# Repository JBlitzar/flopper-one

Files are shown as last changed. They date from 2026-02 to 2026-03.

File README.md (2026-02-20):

# flopper-one

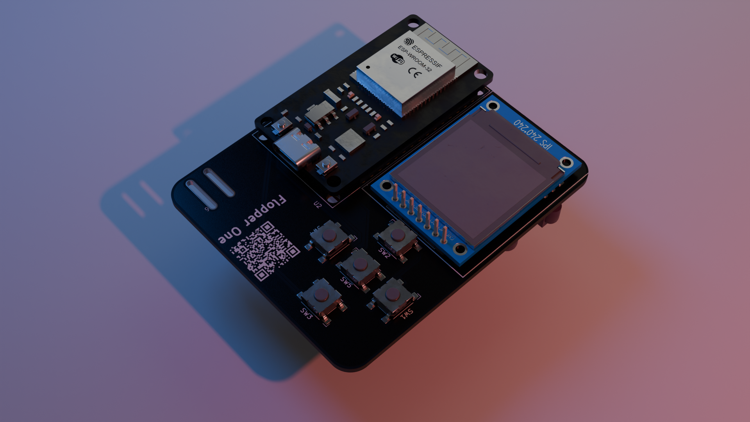
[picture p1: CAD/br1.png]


<!-- <img src="CAD/br2.png"> -->

<table width="100%">
    <tr>
        <td>
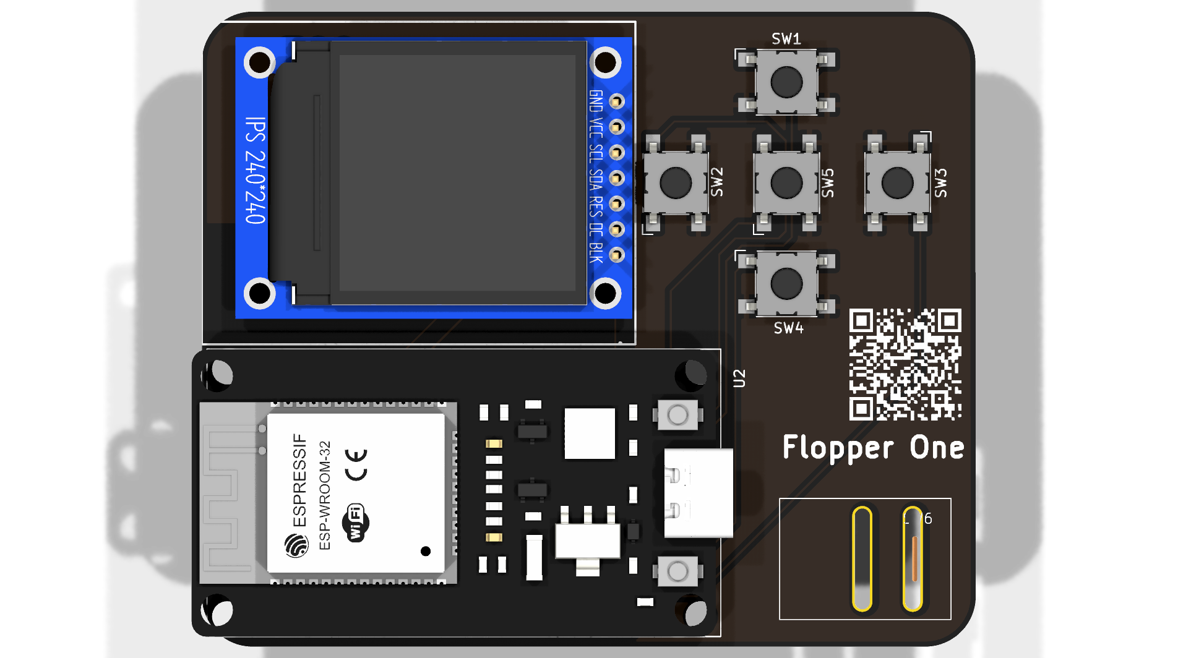
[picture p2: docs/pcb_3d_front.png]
            
        </td>
        <td>
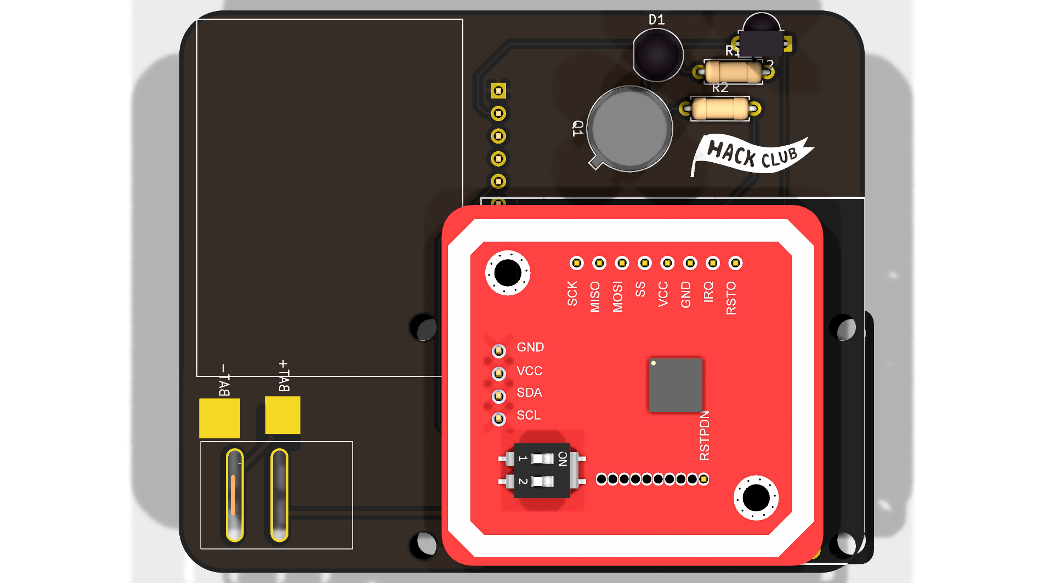
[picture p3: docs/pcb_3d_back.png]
            
        </td>
    </tr>
</table>

Flipper zero-type firmware with an ESP32. Featuring IR, NFC, BLE, wifi, with a dpad and an lcd display. Not designed using any guide!

I've always thought that the flipper zero was pretty cool, but the $200 price point made it seem out of reach.

I joined up blueprint, made the [hackpad](https://github.com/JBlitzar/blitzypad), learned a lot and had a lot of fun.

Then I saw the [sorta flipper zero](https://blueprint.hackclub.com/projects/7192). This was truly inspring. I saw it, and I thought to myself, _I could totally do that_. And it turns out I have like half the parts! The ESP has wifi and bluetooth built in (you usually need to pay like $60 extra for wifi on a flipper), all that's left is to add... all the other stuff.

Since this is my second PCB project, I opted for a module build. In the end, this made the pcb quite crowded and taught me a lot about good routing (and I still had to use the smd TP4056 IC, you'll see later)

Basically, after the ESP, we need a UI, IR, NFC, and RFID.

The UI is some buttons in a dpad and a display.

IR is incredibly easy. It's literally an LED (with some passives sprinkled in), and then a TSOP38238 to recieve.

For NFC/RFID, I opted for the PN532 module. I breifly entertained the idea of using the bare PN532 chip and fully integrating it, but the [datasheet](https://www.nxp.com/docs/en/nxp/data-sheets/PN532_C1.pdf) is 222 pages long and the application circuit (page 212, figure 51) seems pretty involved if I do say so myself.

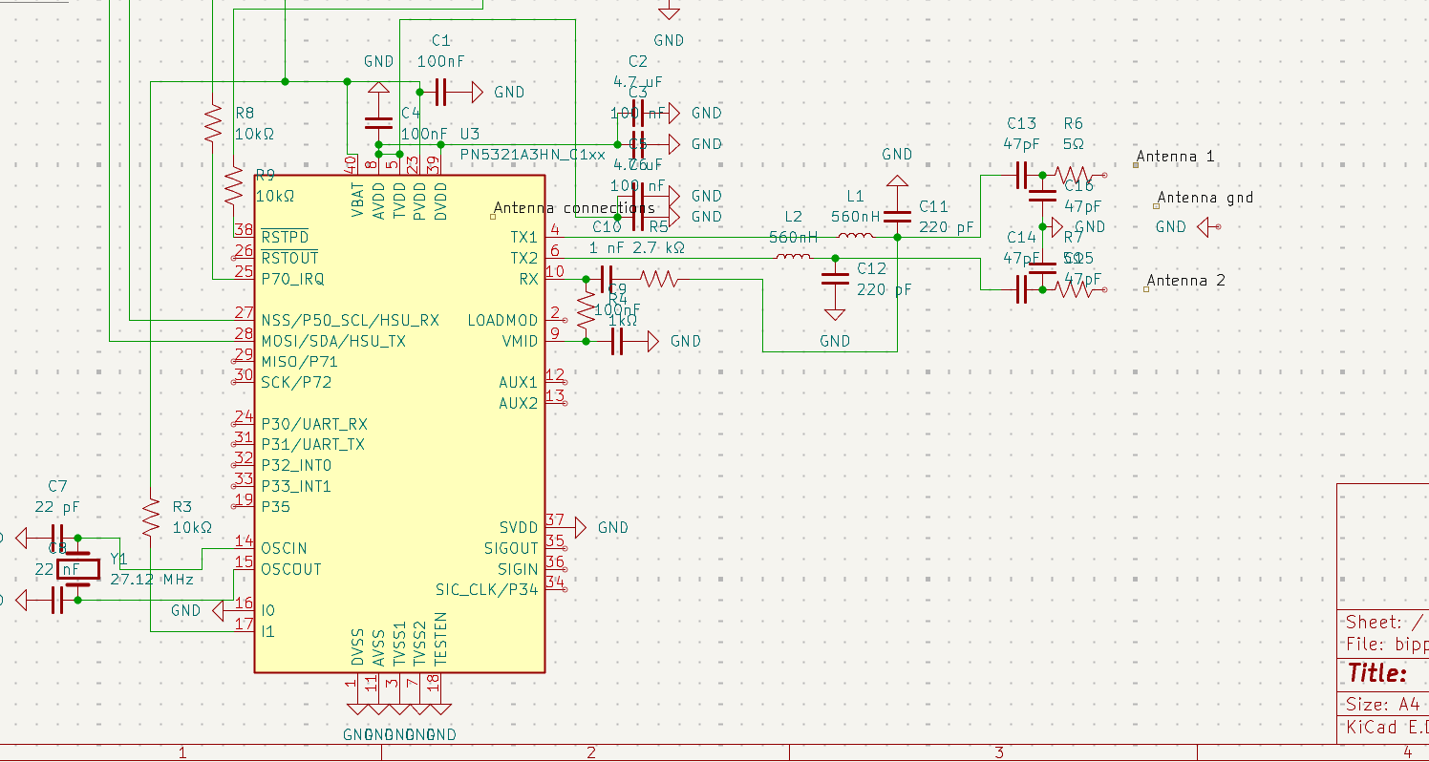
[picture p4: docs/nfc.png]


> _incomplete nfc circuit... yeah its pretty complicated_
>
> At this point it's cheaper AND smaller to just use the module. So that's what I did

Then I thought it'd be fun to add power management. _"fun."_ If only it was simple [like the xiao](https://wiki.seeedstudio.com/xiao_nrf54l15_sense_getting_started/#battery-powered-board)! I added the TP4056 IC because I was feeling fancy. I asked on slack, and it turns out you need a boost converter. To get your 3.7v battery up to 5v... so that it can go back down to 3.3v. I used a module for the boost converter. But I still got to add fun charging status LEDs! Also I got the "opportunity" to google translate Chinese datasheets.

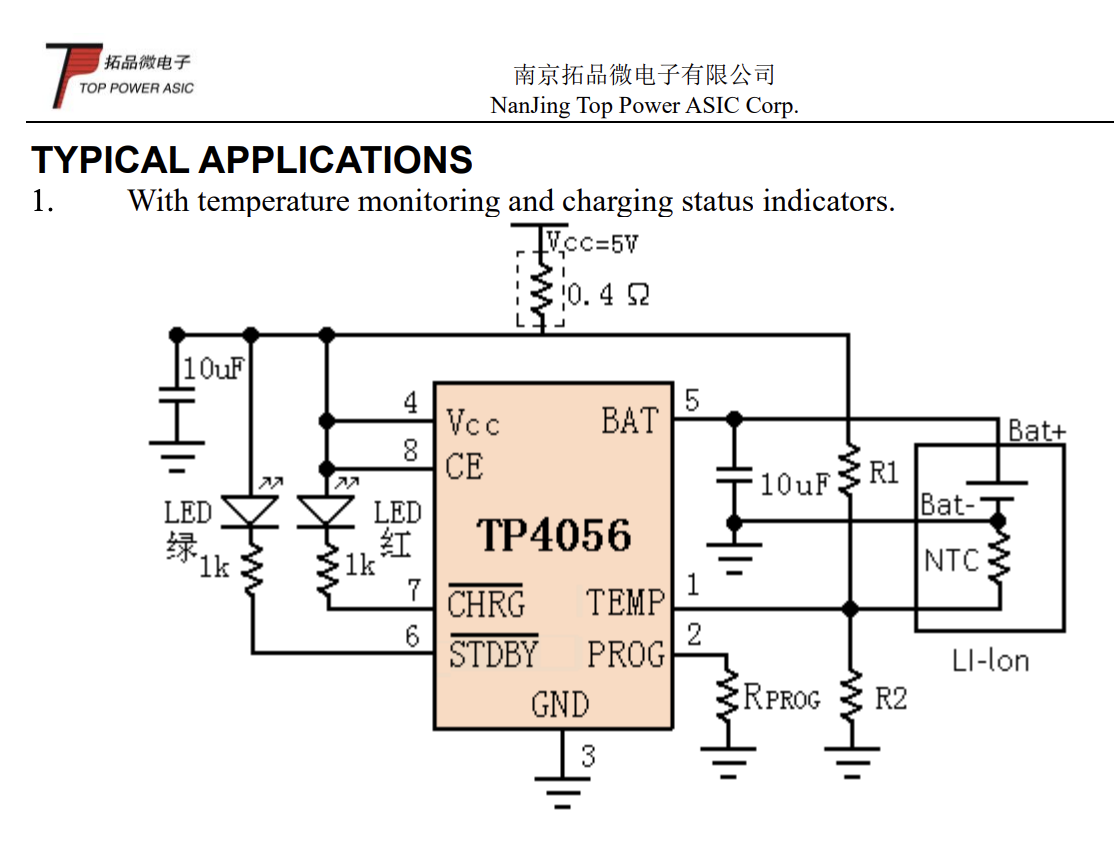
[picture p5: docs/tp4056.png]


I also discovered some... interesting hacks like how the VIN pin on the esp [is actually 5v out](https://esp32.com/viewtopic.php?t=11904) when the usb is plugged in. Meaning we can charge from VIN... and then later discharge also to VIN.

I added a physical switch to prevent backflow. So congratulations, users are now trusted with power supply logic!

## Schematic



## Assembly

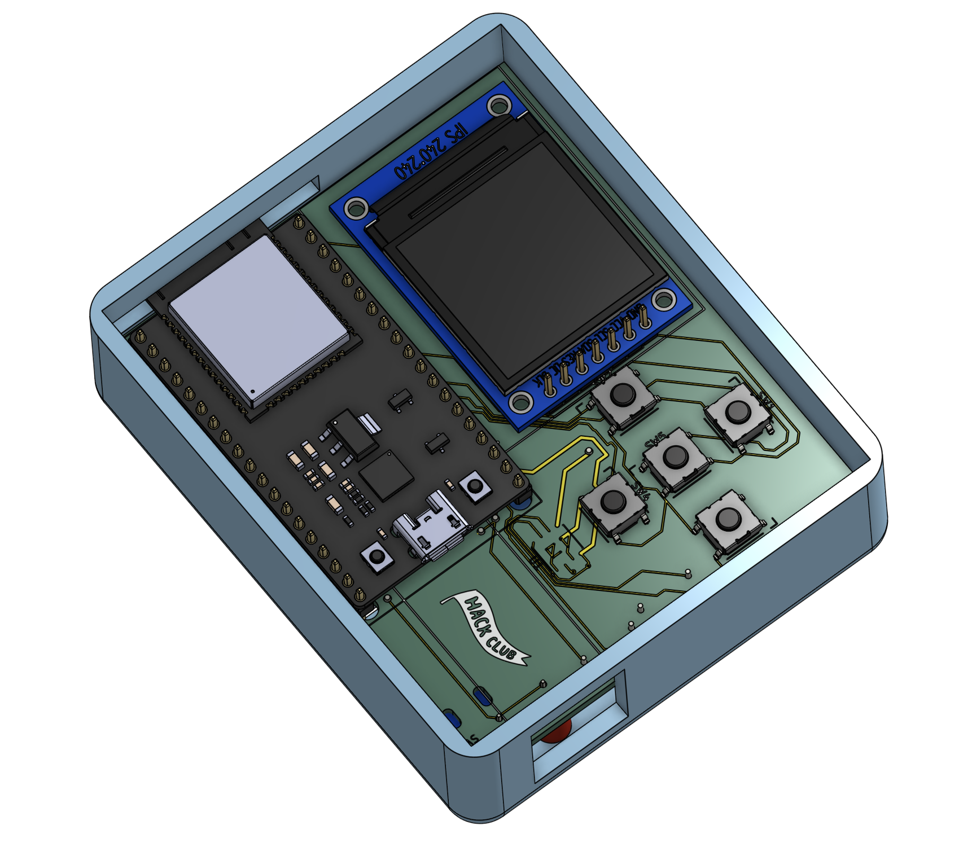
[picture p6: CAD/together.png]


IMPORTANT: See [CAD/README.md](CAD/README.md) for notes.

## PCB



## BOM in table format

see BOM.csv.

This BOM format has been [approved](https://hackclub.slack.com/archives/C09CMJV6V6K/p1770569396266989) by the blueprint team

| Item | Link | Cost  | Amount | total cost of | total | Gotten? |
| --- | --- | ----- | --- | --- | ----- | --- |
| | | | | | 32.15 | FALSE |
| esp32 wroom | already own | 0 | 1 | 0 | | TRUE |
| TSOP38238 | https://www.lcsc.com/product-detail/C141632.html | 0.73  | 1 | 0.73 | | FALSE |
| TSAL6200 | https://www.lcsc.com/product-detail/C55528.html | 0.83  | 1 | 0.83 | | FALSE |
| PN532 | https://www.aliexpress.us/item/3256806254348567.html  | 0.99  | 1 | 0.99 | | FALSE |
| ST7789 | https://www.aliexpress.us/item/2255799995721426.html  | 3.57  | 1 | 3.57 | | FALSE |
| 5x b3fs | https://www.lcsc.com/product-detail/C271750.html | 1.07  | 1 | 1.07 | | FALSE |
| 5x TP4056 (moq) | https://www.lcsc.com/product-detail/C16581.html | 0.91  | 1 | 0.91 | | FALSE |
| lipo battery | already own | 0 | 1 | 0 | | TRUE |
| MT3608 module | https://www.aliexpress.us/item/3256808032184992.html? | 6.77  | 1 | 6.77 | | FALSE |
| 5x PCB (moq) | n/a | 5.3 | 1 | 5.3 | | FALSE |
| switch | already own | 0 | 1 | 0 | | TRUE |
| 1kΩ resistor | Can get for free | 0 | 3 | 0 | | TRUE |
| 47-100Ω resistor | Can get for free | 0 | 1 | 0 | | TRUE |
| 1.2kΩ resistor | Can get substitute for free | 0 | 1 | 0 | | TRUE |
| 10uf capacitor | can get for free | 0 | 2 | 0 | | TRUE |
| 2n2222a (2n2219 substitute) | https://www.lcsc.com/product-detail/C118536.html | 0.77  | 1 | 0.77 | | FALSE |
| LEDS (green, red) | already own | 0 | 2 | 0 | | TRUE |
| header pins | can get for free | 0 | 2 | 0 | | TRUE |
| aliexpress shipping | n/a | 0 | 1 | 0 | | FALSE |
| lcsc shipping | n/a | 11.21 | 1 | 11.21 | | FALSE |

## How to use

Plug the esp into your computer and flash the firmware in /firmware using [platformIO](https://docs.platformio.org/en/latest/core/quickstart.html) in vscode. For now, firmware will run a self-test. In the future, once I verify hardware is working etc, I'll put more details about that in there. (once I have a real UI working)

The reason why firmware's a stub rn is explained in the firmware readme.

See more in [firmware/README.md](firmware/README.md) !

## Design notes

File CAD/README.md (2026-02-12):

# CAD.

## UPDATE

Onshape link: https://cad.onshape.com/documents/9300b75f1e7f06f54f467759/w/c520f6bc2b96db9c93dcf298/e/5722897a21a6c9c2b29192d7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

flopper_one.step is the PCB STEP

flopper_one_case.step is the case STEP

flopper_one_assembly.step is the whole thing together as a STEP

together.png is a picture of the assembly.

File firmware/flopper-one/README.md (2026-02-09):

# Flopper-one firmware

Hello, this is the [platformio](https://platformio.org/) project directory for the flopper one firmware. To not be presumptuous, it's currently set to run a relatively conservative self-test. I've found that things often go wrong, and it's better to debug that early. I have great plans for this in the future. For now it just prints debug statements to the serial console.

All of the hardware pins should be corroborated by the schematic (see [`include/flopper_pins.h`](include/flopper_pins.h))

## A note on AI usage

I used AI for programming portions of this firmware, since I'm not too experienced with platformio. I still feel as if I understand all the code. Don't think of this as a no-effort vibe-coded software stack.

This aligns with Blueprint's AI policy. From the FAQ canvas:

> _Can I use AI?_
>
> _**Yes as guidance/help for code**, no for journals and the rest of your project. This is your project, not AI’s. AI projects will lead to a rejection._

(emphasis mine)

## Roadmap

- Make sure everything works!
- proper menu system
- integrate peripherals, classic flipper functionality (sniff, emit, etc)
  - tv remote emu
  - ble hid
  - easy save / replay on all
- wifi pranks feat. marauder
- polish / boot screen etc
- openhaystack integration? https://github.com/seemoo-lab/openhaystack/tree/main/Firmware/ESP32
- funny usb stuff
- logic analyzer / i2c debugger

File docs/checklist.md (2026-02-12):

# Requirements

- [x] YOUR PROJECT DESIGN IS FULLY COMPLETE:
  - [x] It is an original, customized design by you, and is not a direct copy of any guide
  - [x] It has a complete CAD assembly, with all components (including electronics) [CAD/README.md](/CAD/README.md)
  - [x] You have firmware present, even if it's untested [firmware/](/firmware/)
  - [x] You have sanity checked your design with someone else (in #blueprint)
- [x] YOUR GITHUB REPOSITORY CONTAINS ALL OF YOUR PROJECT FILES:
  - [x] A BOM, in CSV format in the root directory, WITH LINKS [BOM.csv](/BOM.csv)
  - [x] The source files for your PCB, if you have one (.kicad_pro, .kicad_sch, gerbers.zip, etc) [/PCB](/PCB)
  - [x] A .STEP file of your project's 3D CAD model as well as the source design file format (.f3d, .FCStd, etc) [onshape link](https://cad.onshape.com/documents/9300b75f1e7f06f54f467759/w/c520f6bc2b96db9c93dcf298/e/5722897a21a6c9c2b29192d7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) also in [CAD/README.md](/CAD/README.md)
  - [x] ANY other files that are part of your project (firmware, libraries, references, etc) [/PCB](/PCB) should contain all "extra" files
  - [x] Everything easily readable and organized into folders
  - [x] A .STEP file with all electronics and CAD (required for approval) [CAD/flopper_one_assembly.step](/CAD/flopper_one_assembly.step)
- [x] YOUR README.md FILE CONTAINS THE FOLLOWING:
  - [x] A short description of what your project is [README.md](/README.md)
  - [x] A couple sentences on why you made the project [README.md](/README.md)
  - [x] A couple sentences on how to use your project [README.md](https://github.com/JBlitzar/flopper-one?tab=readme-ov-file#how-to-use)
- [x] PICTURES OF YOUR PROJECT:
  - [x] A screenshot of a full 3D model with your project (see [CAD/together.png](/CAD/together.png))
  - [x] A screenshot of your PCB, if you have one (see [README.md](https://github.com/JBlitzar/flopper-one?tab=readme-ov-file#pcb))
  - [x] A wiring diagram, if applicable (see [schematic in README](https://github.com/JBlitzar/flopper-one?tab=readme-ov-file#schematic))
  - [x] A BOM in table format at the end of the README, with links (see [end of README](https://github.com/JBlitzar/flopper-one?tab=readme-ov-file#bom-in-table-format))
- [x] YOU DO NOT HAVE:
  - X AI Generated READMEs, Journal entries, or images of your project
  - X Designs taken from other people
  - X Missing firmware/software

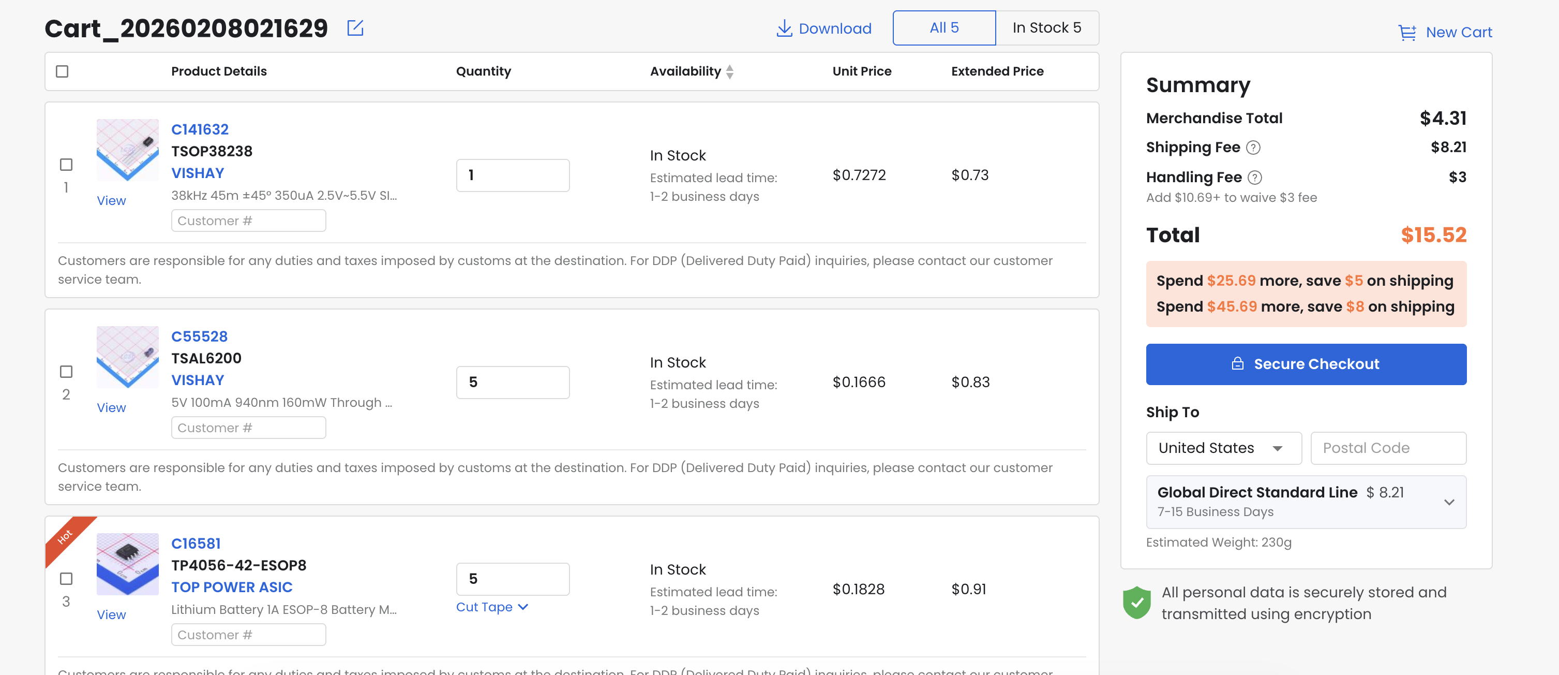
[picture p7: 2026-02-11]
docs/lcsc_cart.png

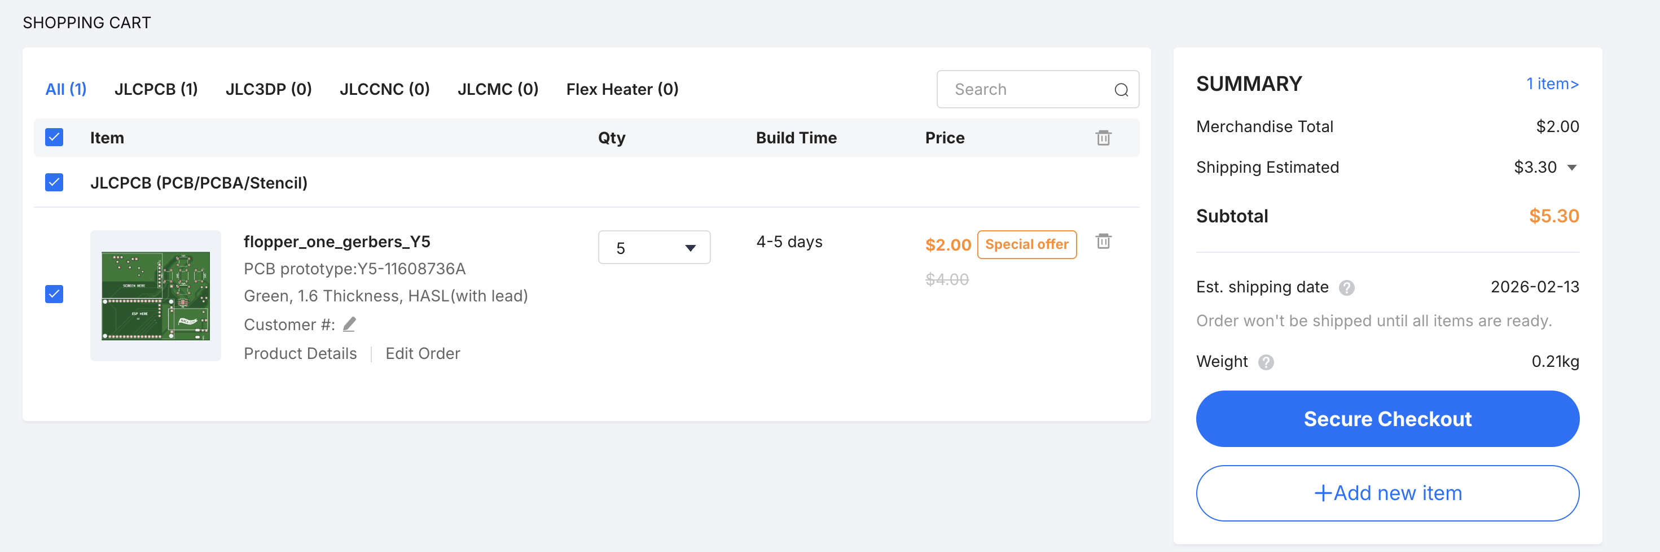
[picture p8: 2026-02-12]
docs/jlcpcb_cart.png

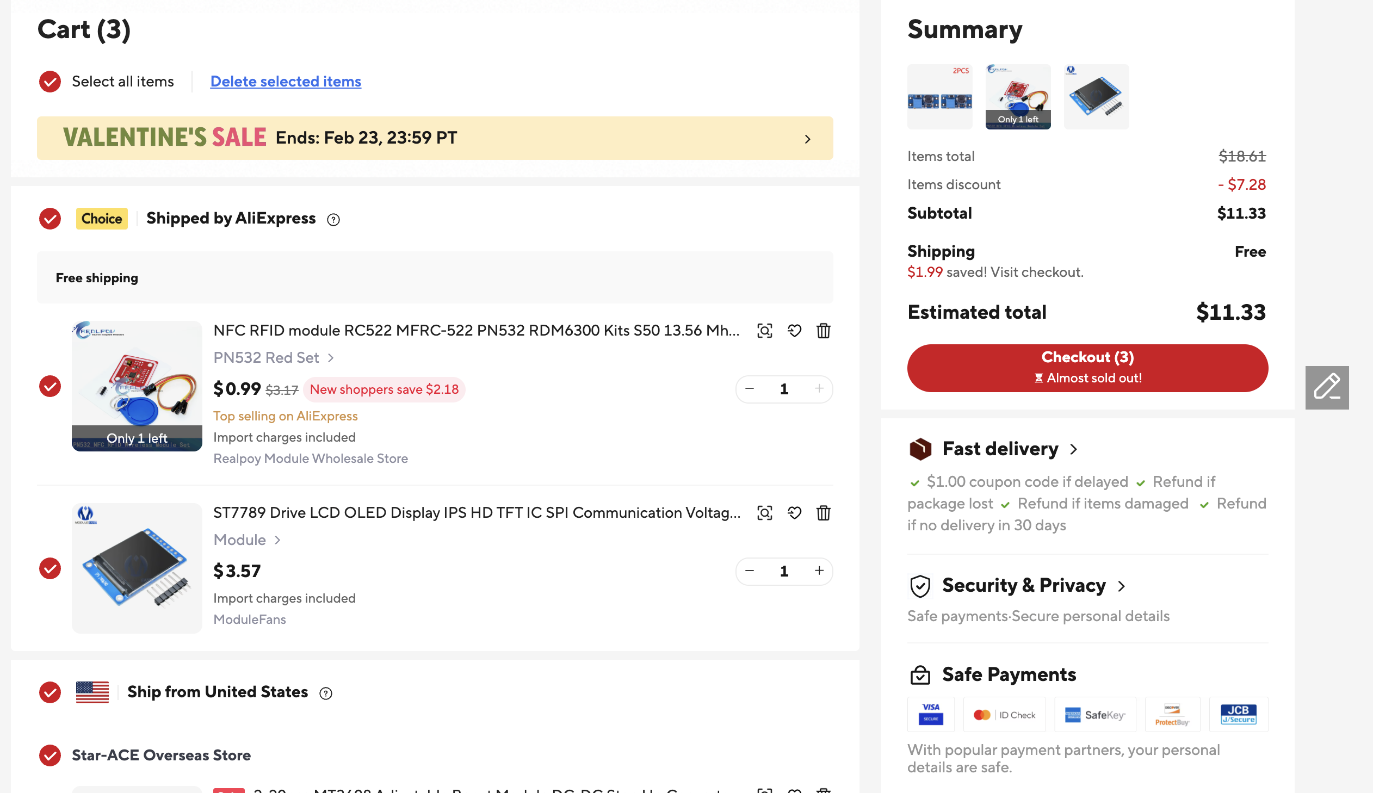
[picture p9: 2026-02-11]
docs/aliexpress_cart.png

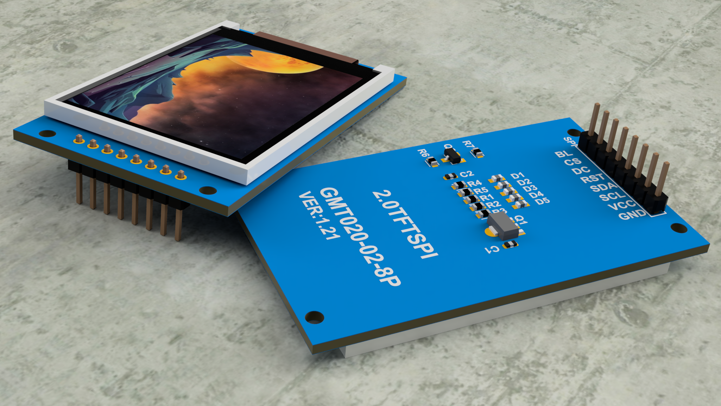
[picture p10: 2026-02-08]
PCB/flopper_one/st7789/render.png

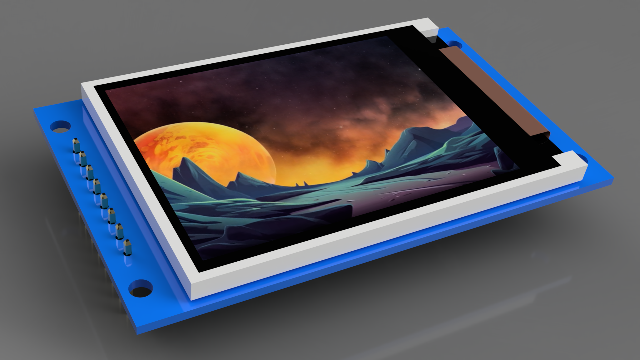
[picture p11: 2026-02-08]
PCB/flopper_one/st7789/Display_TFT-ST7789-240X320.png

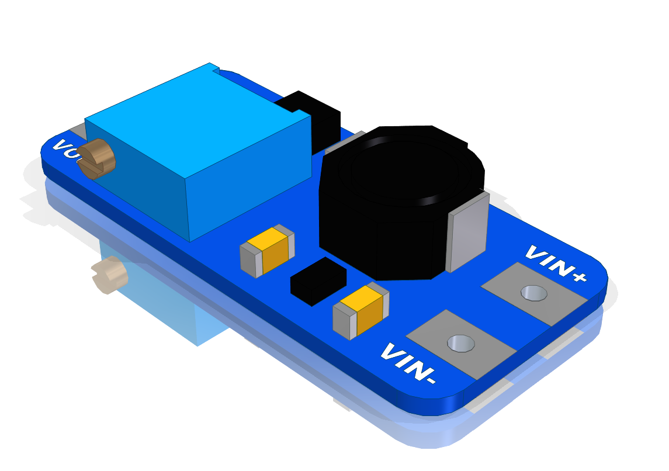
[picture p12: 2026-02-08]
PCB/flopper_one/mt3608-1/MT3608 - Module.PNG

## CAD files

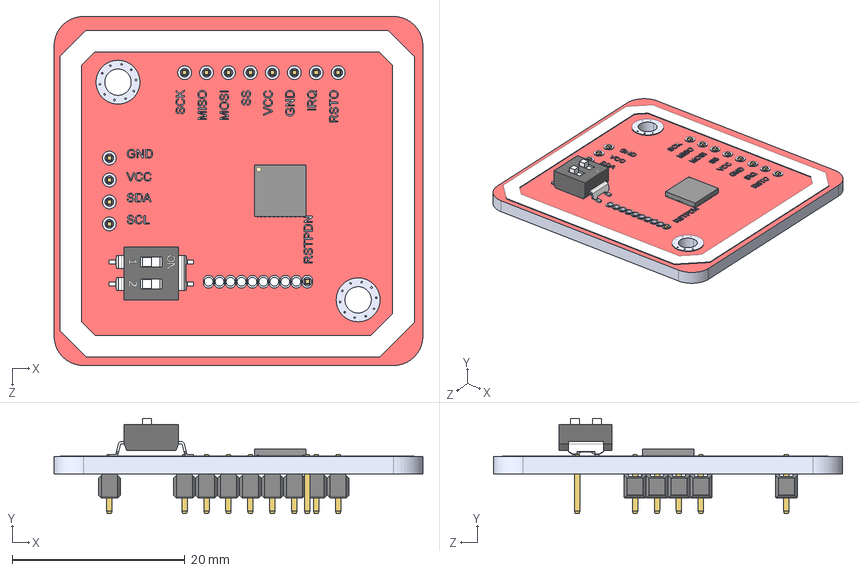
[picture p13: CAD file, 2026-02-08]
PCB/flopper_one/PN532_NFC_Assembly.STEP
42.7 x 11.0 x 40.4 mm
NFC_MODULE_1
Pin Stand 2.54mm_1 x 12
QFN40 (6x6)_1
Switch_2_1
pin_my_1 x 13

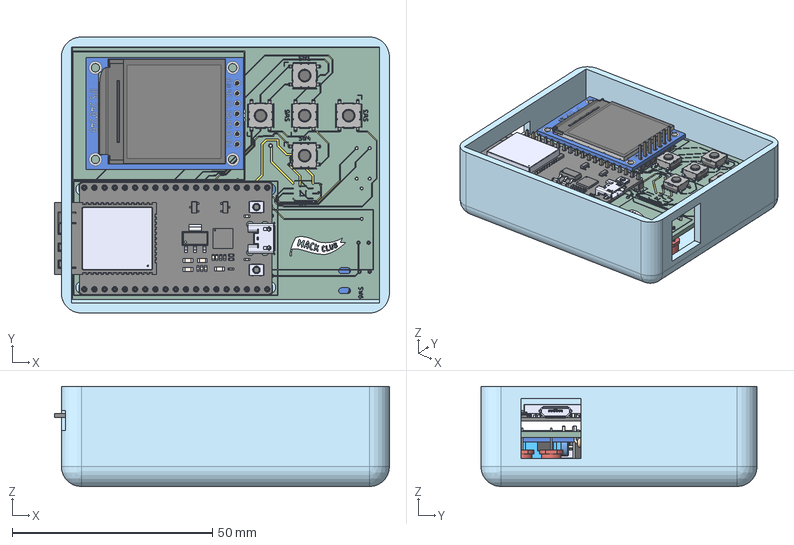
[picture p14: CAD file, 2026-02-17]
CAD/flopper_one_assembly.step
83.7 x 69.0 x 25.0 mm
flopper_one_silkscreen x 203
SW_SPST_Omron_B3FS-100xP x 5
flopper_one_copper x 50
flopper_one_via x 7
R_Axial_DIN0207_L6.3mm_D2.5mm_P7.62mm_Horizontal x 5
flopper_one_PCB
CP_Axial_L10.0mm_D4.5mm_P15.00mm_Horizontal x 2
LED_D5.0mm x 2
MT3608-Module
PinHeader_1x07_P2.54mm_Vertical
LED_D5.0mm_IRBlack
TO-39-3
PinHeader_1x04_P2.54mm_Vertical
0603 Capacitor
0603 Resistor x 3
1.3 TFT IPS - Board
1.3 TFT IPS - Flush Reverse Mount
SOT-23
Vishay_MINICAST-3Pin
pin_my_1 x 26
QFN40 (6x6)_1 x 5
Pin Stand 2.54mm_1 x 12
Switch_2_1
NFC_MODULE_1
board x 39
header x 76
components^DEVKIT V1 ESP32-WROOM-32 x 48
ESP32-WROOM-32D x 41
CP2102N-A01-GQFN28 x 31
AMS1117-3.3 x 6
button x 14
SS8050-G x 8
micro usb x 12

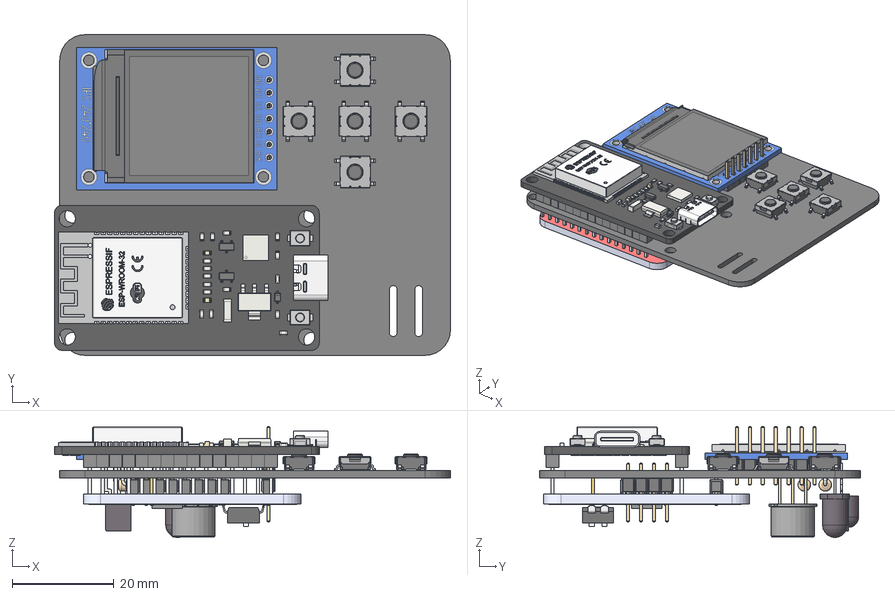
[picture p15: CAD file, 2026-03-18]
CAD/flopper_one.step
77.8 x 63.0 x 21.8 mm
PinHeader_1x07_P2.54mm_Vertical
1.3 TFT IPS - Board
1.3 TFT IPS - Flush Reverse Mount
0603 Resistor x 3
0603 Capacitor
SOT-23
SW_SPST_Omron_B3FS-100xP x 5
esp32_Wroom_30pins_C-Type x 143
R_Axial_DIN0207_L6.3mm_D2.5mm_P7.62mm_Horizontal x 2
Vishay_MINICAST-3Pin
TO-39-3
LED_D5.0mm_IRBlack
PinHeader_1x04_P2.54mm_Vertical
NFC_MODULE_1
Pin Stand 2.54mm_1 x 12
QFN40 (6x6)_1
Switch_2_1
pin_my_1 x 13
flopper_one_PCB

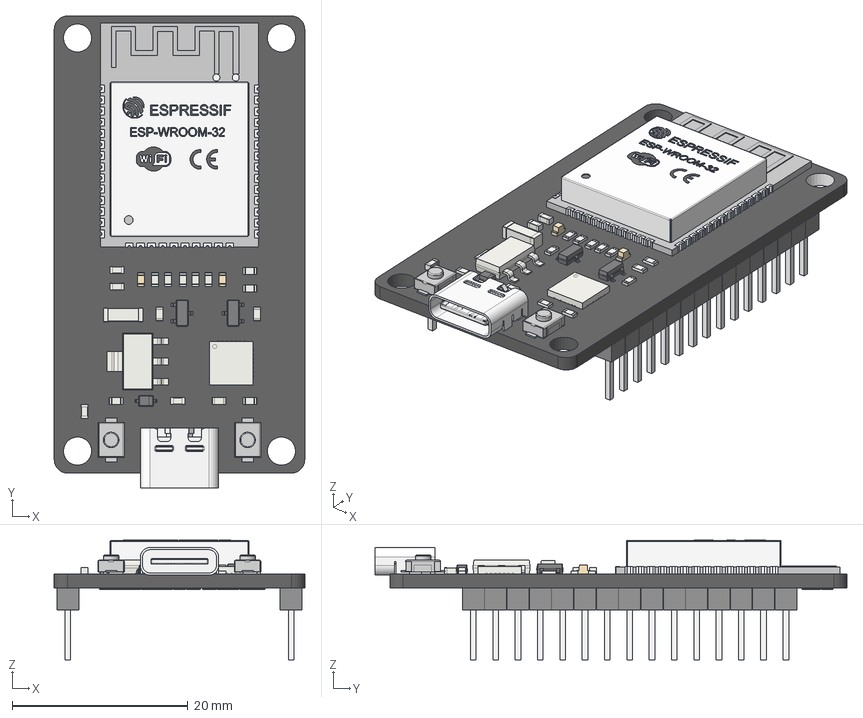
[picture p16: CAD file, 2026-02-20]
PCB/flopper_one/esp32-wroom-30pin-c-type-1.snapshot.8/esp32_Wroom_30pins_C-Type.STEP
28.5 x 53.7 x 13.7 mm

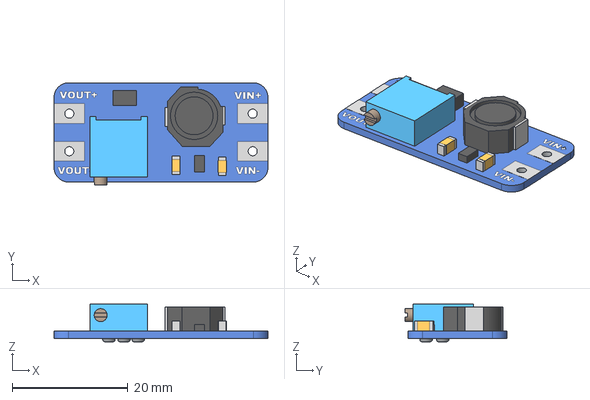
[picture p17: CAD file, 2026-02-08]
PCB/flopper_one/mt3608-1/MT3608-Module.stp
37.0 x 17.7 x 6.50 mm

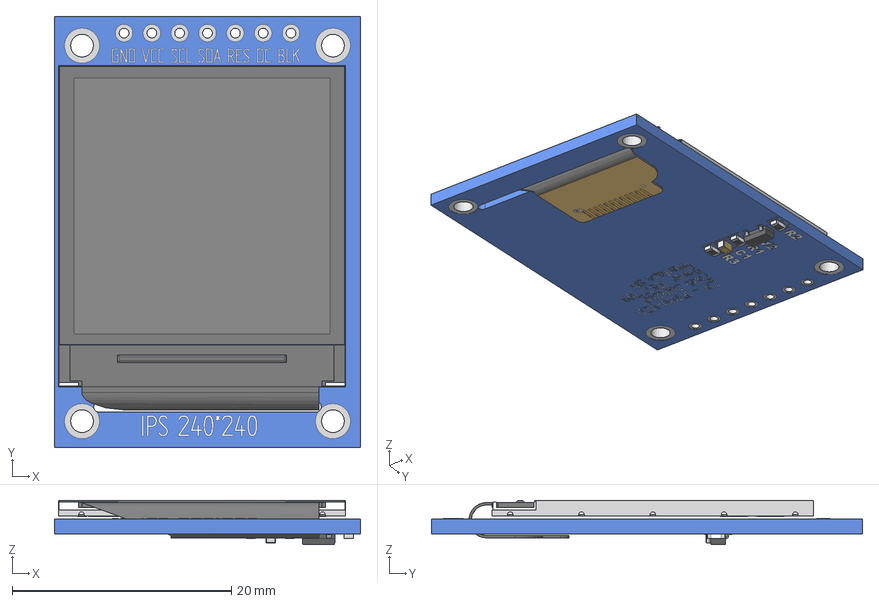
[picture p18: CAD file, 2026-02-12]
PCB/flopper_one/st7789.stp
27.9 x 39.4 x 4.06 mm
1.3 TFT IPS - Board
1.3 TFT IPS - Flush Reverse Mount
0603 Resistor x 3
0603 Capacitor
SOT-23

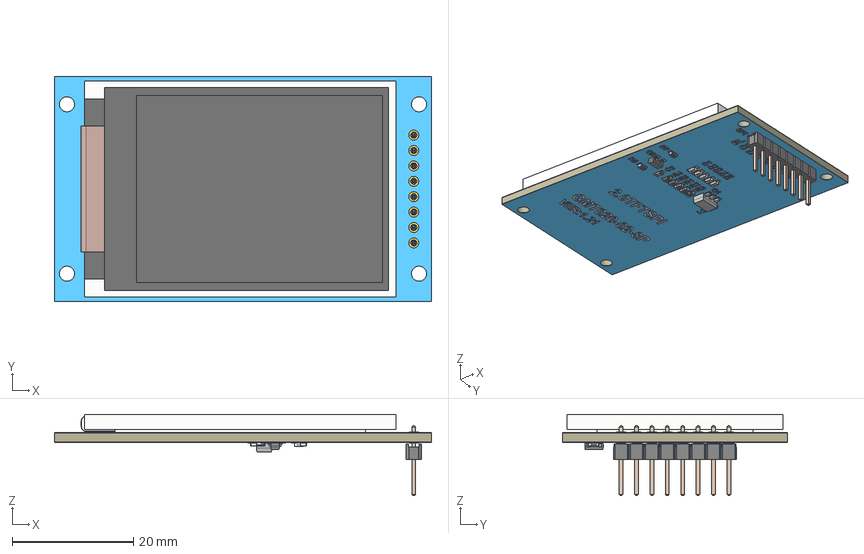
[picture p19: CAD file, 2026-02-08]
PCB/flopper_one/st7789/Display TFT-ST7789-240X320 V2.step
62.2 x 37.2 x 13.4 mm
Board
64-copper
1-soldermask
64-soldermask
6130xx11121_PIN x 8
SOT23
DIODE_PGB-0603MP x 5
5576557.f3d x 7
CAP_0603 x 2
SOT89
1-copper
Text
Screen support
Ribon cable
Glass

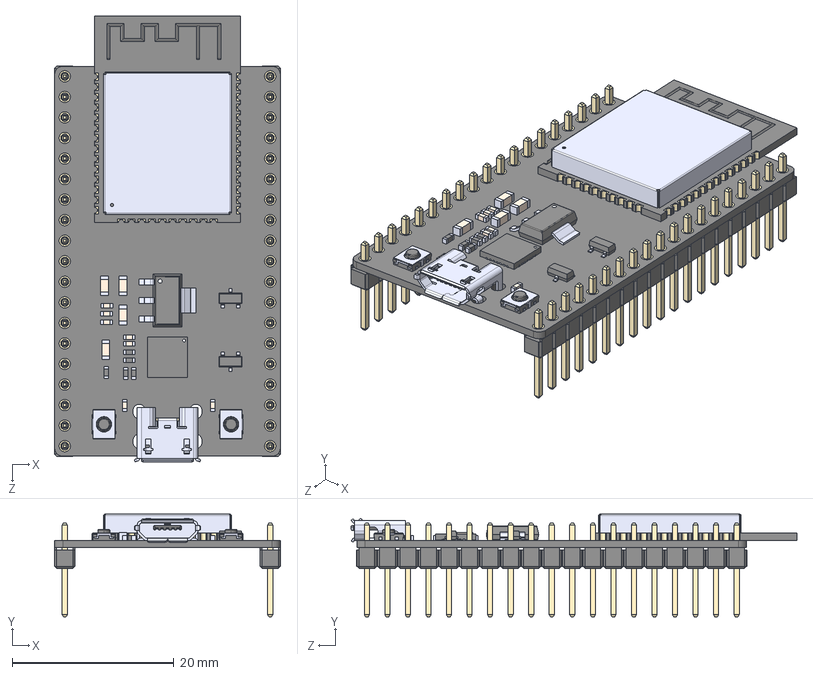
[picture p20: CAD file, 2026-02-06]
PCB/flopper_one/wroom/DEVKIT_V1_ESP32-WROOM-32.step
27.9 x 12.7 x 55.1 mm
board
header x 2
ESP32-WROOM-32D
micro usb
button x 2
CP2102N-A01-GQFN28
AMS1117-3.3
SS8050-G
components^DEVKIT V1 ESP32-WROOM-32

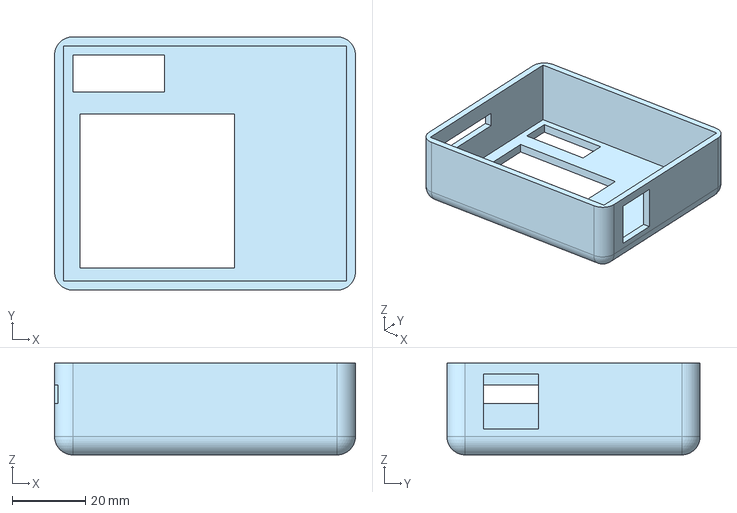
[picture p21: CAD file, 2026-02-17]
CAD/flopper_one_case.step
82.0 x 69.0 x 25.0 mm

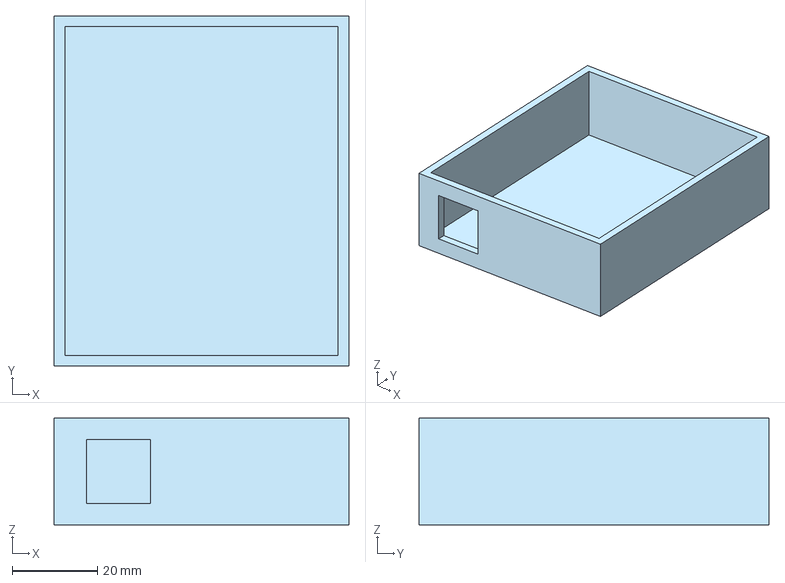
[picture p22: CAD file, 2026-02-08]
CAD/case.step
69.0 x 82.0 x 25.0 mm

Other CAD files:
CAD/flopper.blend

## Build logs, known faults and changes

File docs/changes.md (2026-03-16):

# TODO fr

reflow all joints

Wire a new mt3608 bodge with the new module. You'll need to bodge across, swapping + and - on both vin and vout.

Cut the corner pins off of the board. Melt the plastic and cut the metal?

the EN ESP PIN should lead nowhere.

The gp23 ESP PIN should lead to the pad under the VIN pin

The VIN ESP PIN should lead to the pad under the 3v3 pin

The 3v3 ESP PIN should lead to the pad under the en pin.

In kicad-speak:

> Traces that currently go to vcc, go to en.
> Traces that currently go to gp 23, go to vin.
> Traces that currently go to vin, go to 3v3

Change the pins in the header file to match the scam mirrored pinout.

solder in the lcsc parts

cross fingers!

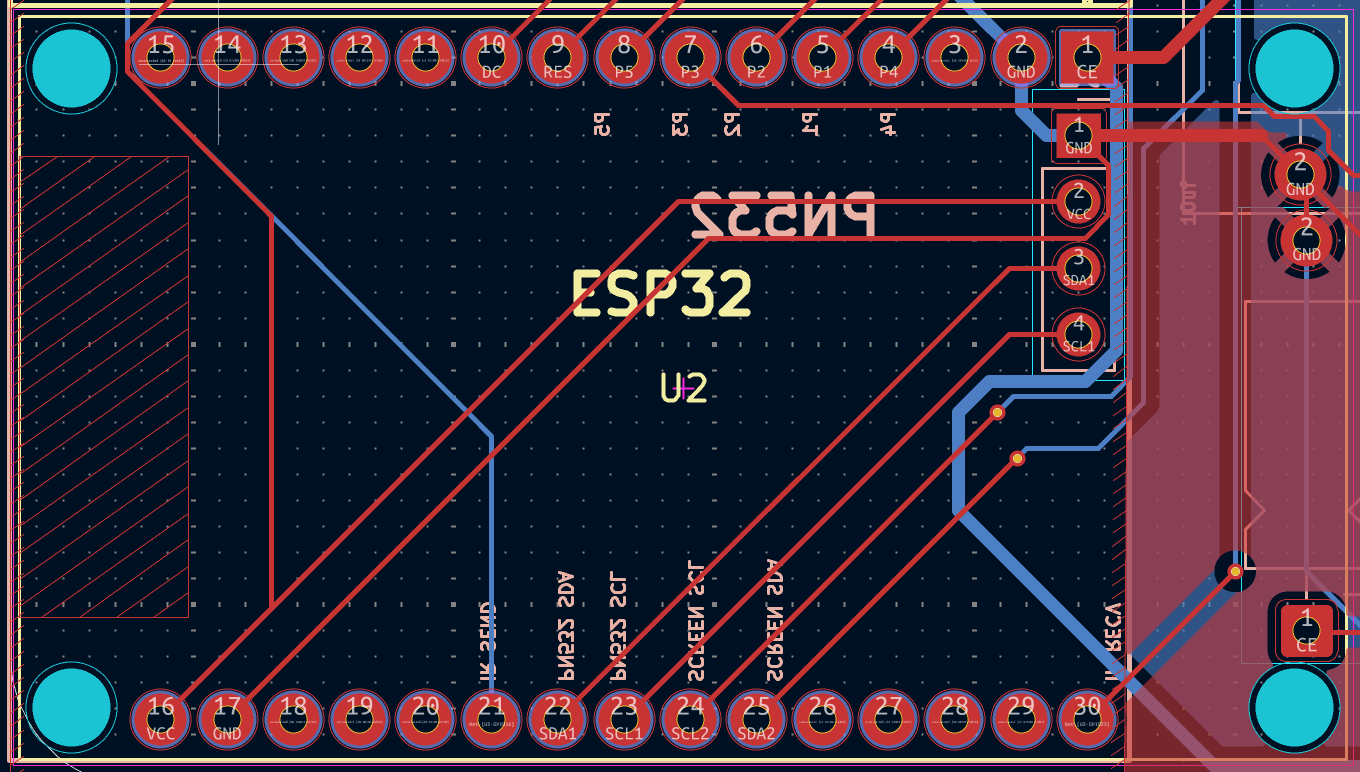
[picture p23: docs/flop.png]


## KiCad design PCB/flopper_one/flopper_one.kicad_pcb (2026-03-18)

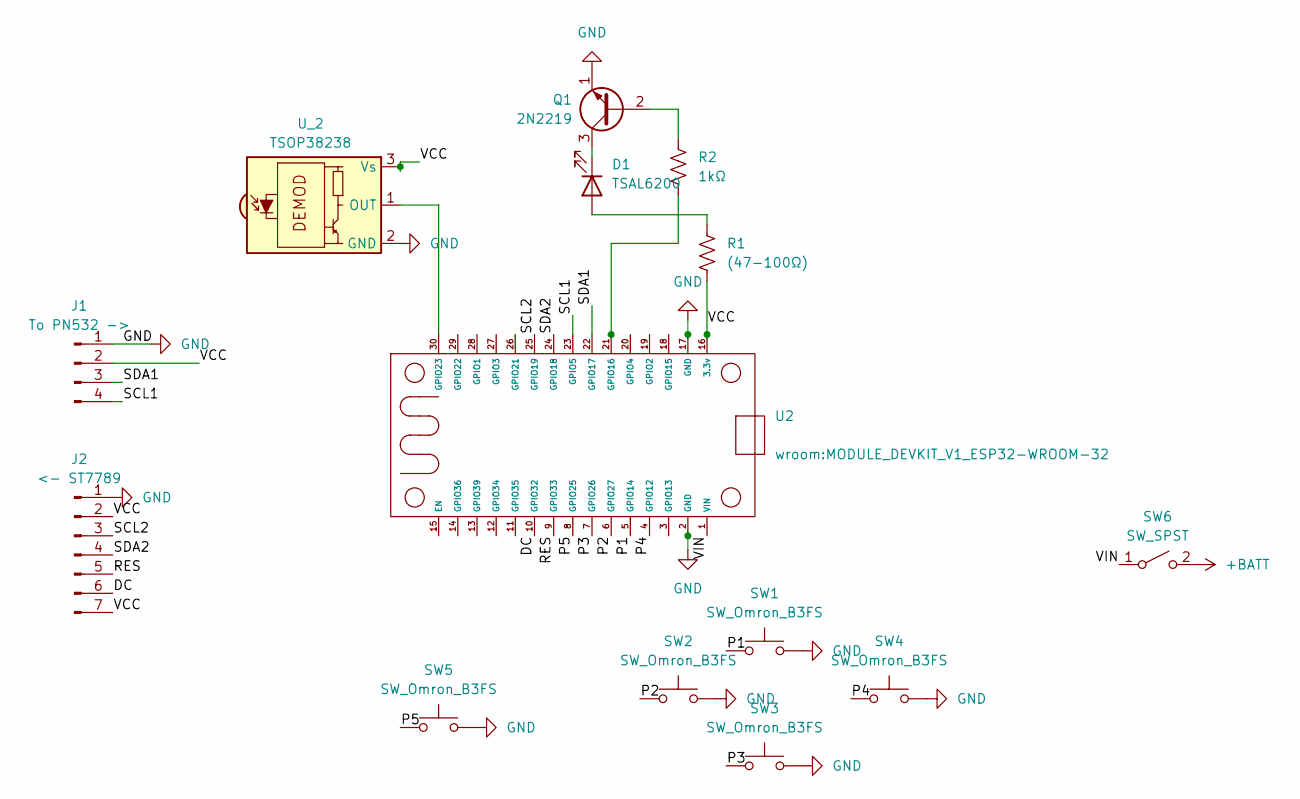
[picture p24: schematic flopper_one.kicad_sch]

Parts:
D1: TSAL6200; LED_D5.0mm_IRBlack
J1: To PN532 ->; PinHeader_1x04_P2.54mm_Vertical
J2: <- ST7789; PinHeader_1x07_P2.54mm_Vertical
Q1: 2N2219; TO-39-3
R1: (47-100Ω); R_Axial_DIN0207_L6.3mm_D2.5mm_P7.62mm_Horizontal
R2: 1kΩ; R_Axial_DIN0207_L6.3mm_D2.5mm_P7.62mm_Horizontal
SW1, SW2, SW3, SW4, SW5: SW_Omron_B3FS; SW_SPST_Omron_B3FS-100xP
SW6: SW_SPST; my_switch
U2: MODULE_DEVKIT_V1_ESP32-WROOM-32
U_2: TSOP38238; Vishay_MINICAST-3Pin

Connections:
+BATT: SW6.2 (B)
/DC: J2.6, U2.10 (GPIO32)
/P1: SW1.1, U2.5 (GPIO14)
/P2: SW2.1, U2.6 (GPIO27)
/P3: SW3.1, U2.7 (GPIO26)
/P4: SW4.1, U2.4 (GPIO12)
/P5: SW5.1, U2.8 (GPIO25)
/RES: J2.5, U2.9 (GPIO33)
/SCL1: J1.4 (GND), U2.23 (GPIO5)
/SCL2: J2.3, U2.25 (GPIO19)
/SDA1: J1.3 (TX), U2.22 (GPIO17)
/SDA2: J2.4, U2.24 (GPIO18)
/VCC: J1.2 (RX), J2.2, J2.7, R1.2, U2.16 (3.3v), U_2.3 (Vs)
/VIN: SW6.1 (A), U2.1 (VIN)
GND: J1.1 (VCC), J2.1, Q1.1 (E), SW1.2, SW2.2, SW3.2, SW4.2, SW5.2, U2.2 (GND), U2.17 (GND), U_2.2 (GND)
unnamed: D1.2 (A), R1.1
unnamed: D1.1 (K), Q1.3 (C)
unnamed: Q1.2 (B), R2.1
unnamed: R2.2, U2.21 (GPIO16)
unnamed: U2.30 (GPIO23), U_2.1 (OUT)

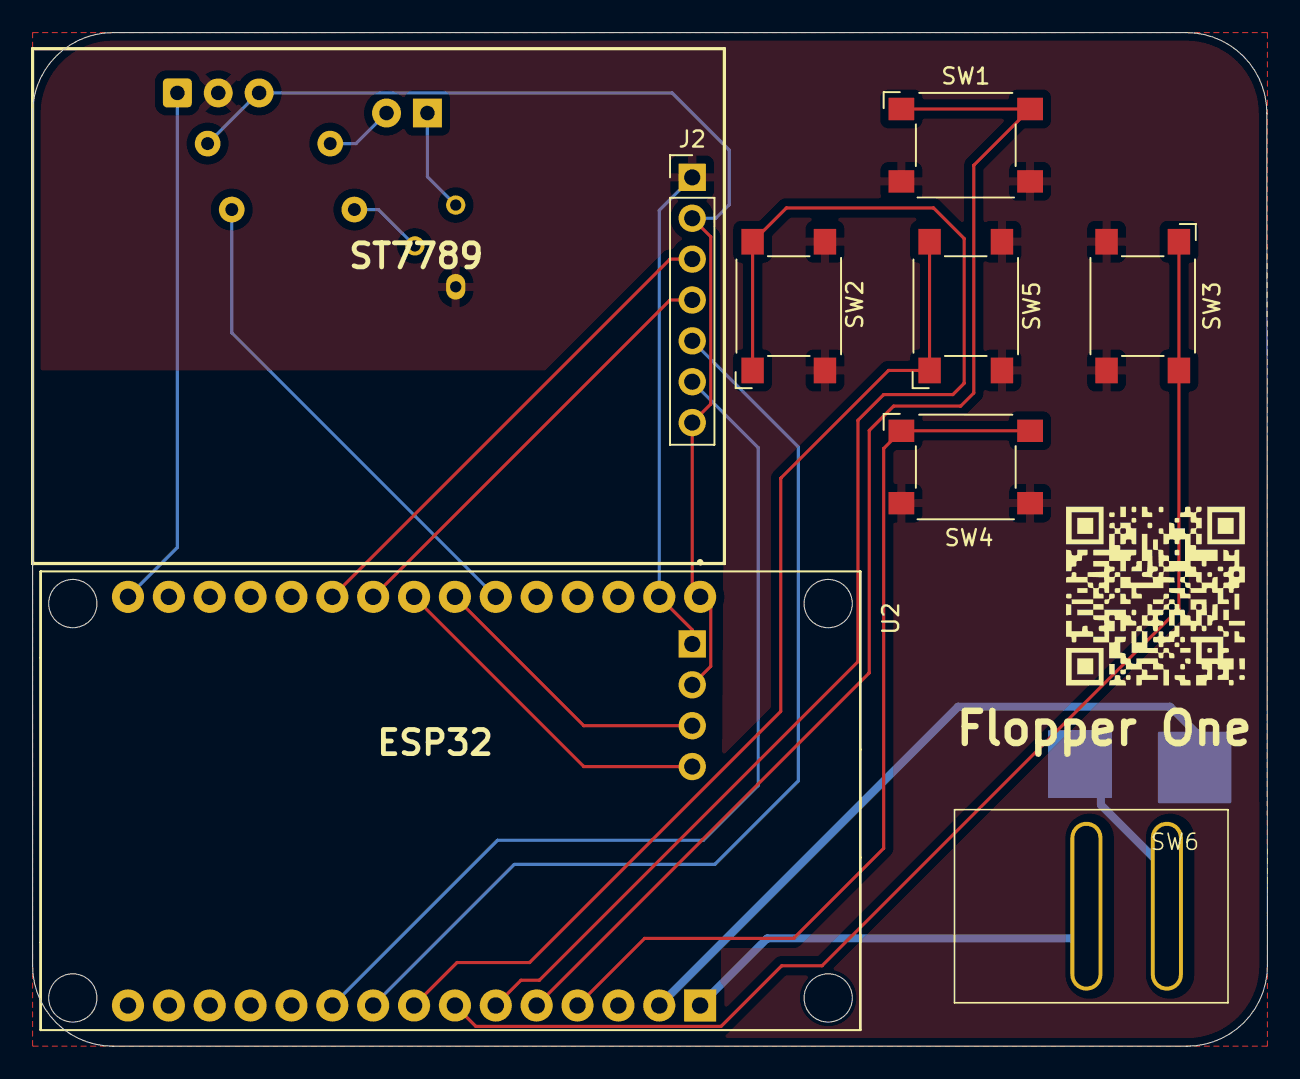
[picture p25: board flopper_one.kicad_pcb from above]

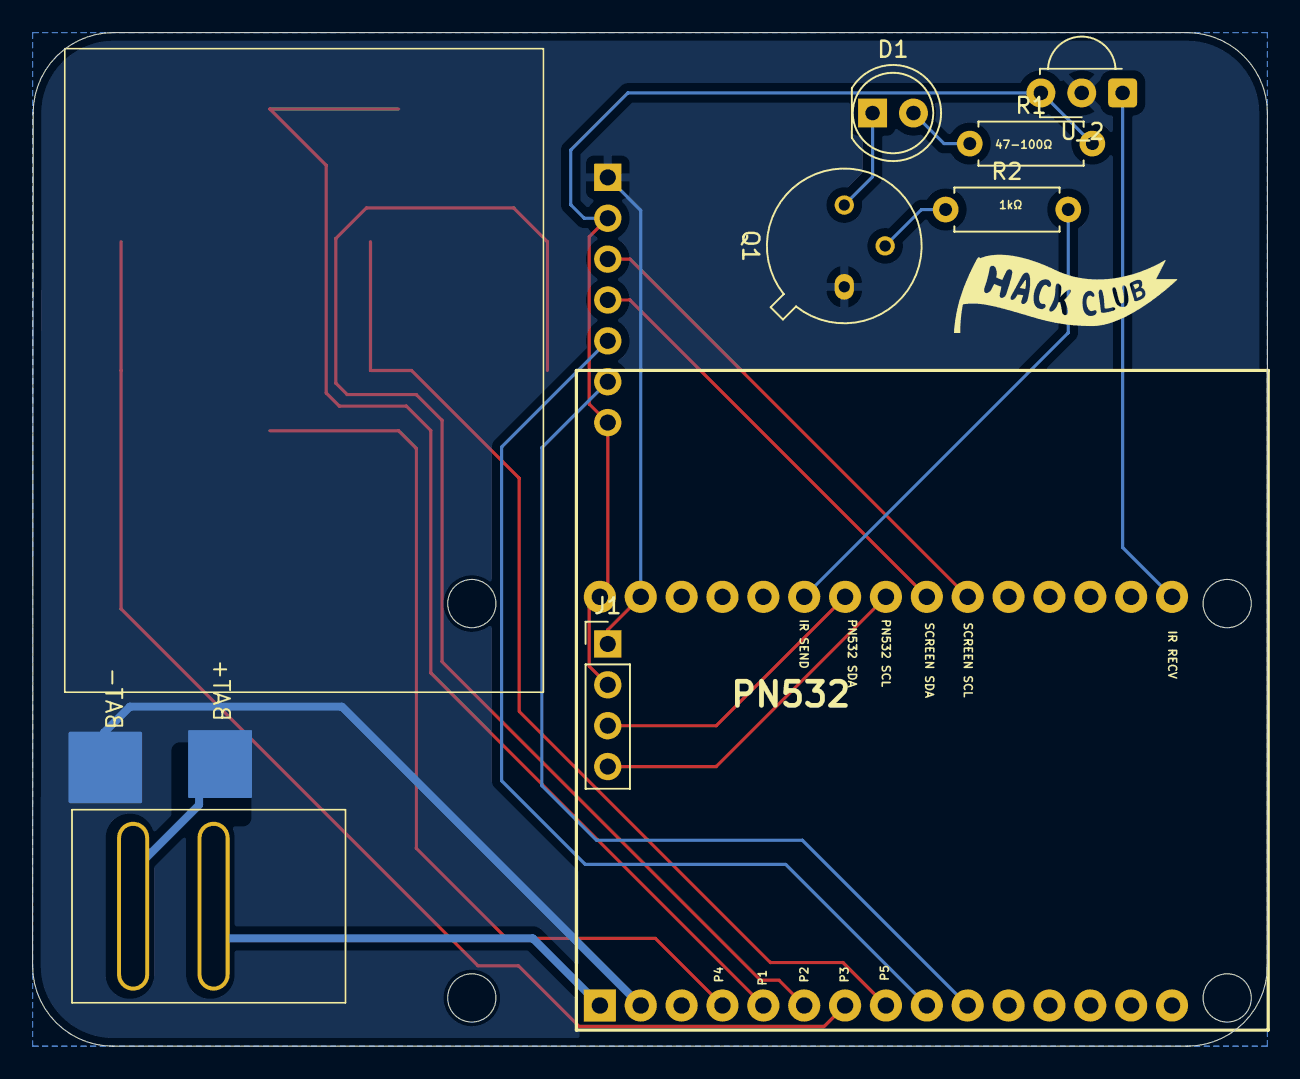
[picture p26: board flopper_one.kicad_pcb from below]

Board: 2 copper layers, 76.8 x 63.0 mm, 14 parts (6 on the bottom side), 19 nets.

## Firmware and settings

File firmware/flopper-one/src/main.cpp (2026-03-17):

#include <Arduino.h>

#include "menu_tree.h"
#include "menu_manager.h"
#include "input_dispatcher.h"
#include "log.h"

void setup()
{
    Serial.begin(115200);
    delay(100);
    flopper::build_menu_tree();
    flopper::MenuManager::get_instance().set_root(&flopper::root);
    flopper::InputDispatcher::get_instance().push(&flopper::MenuManager::get_instance());

    flopper::log::printf("BOOT", "boot %s %s", __DATE__, __TIME__);
}

void loop()
{
    flopper::InputDispatcher::get_instance().poll();
    flopper::MenuManager::get_instance().tick();
}

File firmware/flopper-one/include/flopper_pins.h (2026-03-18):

#pragma once

#include <Arduino.h>

namespace flopper::pins
{

    // GPIO pins
    static constexpr uint8_t TSOP_OUT = 23; // TSOP IR receiver out
    static constexpr uint8_t DPAD_UP = 14;  // normal buttons
    static constexpr uint8_t DPAD_LEFT = 27;
    static constexpr uint8_t DPAD_RIGHT = 12;
    static constexpr uint8_t DPAD_DOWN = 26;
    static constexpr uint8_t DPAD_CENTER = 25;

    static constexpr uint8_t PN532_SDA = 17; // pn532 nfc/rfid thing
    static constexpr uint8_t PN532_SCL = 15;

    // Display (ST7789) is SPI, not I2C.
    static constexpr uint8_t DISP_SCL = 19; // SPI SCLK (as wired)
    static constexpr uint8_t DISP_SDA = 18; // SPI MOSI (as wired)
    static constexpr uint8_t DISP_DC = 32;  // SPI D/C (as wired)

    // Preferred names
    static constexpr uint8_t DISP_SCLK = DISP_SCL;
    static constexpr uint8_t DISP_MOSI = DISP_SDA;

    static constexpr uint8_t IR_LED = 16;

}

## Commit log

2026-02-06 routed switches
    [flopper_one.kicad_pcb]
2026-02-06 start routing ir
    [flopper_one.kicad_pcb]
2026-02-07 use labels
    [flopper_one.kicad_sch]
2026-02-07 routed the pcb
    [flopper_one.kicad_pcb, flopper_one.kicad_sch]
2026-02-07 add battery
    [flopper_one.kicad_pcb, flopper_one.kicad_sch]
2026-02-08 added like power circuits fr
    [flopper_one.kicad_pcb, flopper_one.kicad_sch]
2026-02-08 fix battery rq
    [flopper_one.kicad_pcb, flopper_one.kicad_sch]
2026-02-08 clean stuff up
    [flopper_one.kicad_pcb]
2026-02-08 add nice 3d models
    [Display TFT-ST7789-240X320 V2.step, MT3608-Module.stp, PN532_NFC_Assembly.STEP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]
2026-02-08 gerbers, bom
    [BOM.csv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]
2026-02-08 cad folder
    [flopper_one.kicad_pcb]
2026-02-08 lowk wrote the readme
    [flopper_one.step]
2026-02-08 fix minor error
    [flopper_one.kicad_pcb, flopper_one.kicad_sch]
2026-02-08 move stuff around
    [flopper_one.kicad_pcb, flopper_one.kicad_sch]
2026-02-09 uhm fix drc errors
    [flopper_one.kicad_pcb]
2026-02-09 shove cap again
    [flopper_one.kicad_pcb]
2026-02-09 yum yum clean traces
    [flopper_one.kicad_pcb]
2026-02-09 "quick" schematic fix
    [flopper_one.kicad_pcb, flopper_one.kicad_sch]
2026-02-09 update bom
    [BOM.csv]
2026-02-09 flip r6
    [flopper_one.kicad_pcb]
2026-02-09 gerber cicd
    [flopper_one-B_Cu.gbr, flopper_one-B_Mask.gbr, flopper_one-B_Paste.gbr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]
2026-02-10 pretty pictures
    [flopper.blend]
2026-02-10 make thicker and add gnd pour
    [flopper_one-B_Cu.gbr, flopper_one-B_Mask.gbr, flopper_one-B_Paste.gbr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]
2026-02-11 free shipping
    [BOM.csv]
2026-02-11 rm that one resistor + gnd pour
    [flopper_one-B_Cu.gbr, flopper_one-B_Mask.gbr, flopper_one-B_Paste.gbr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]
2026-02-11 make more things thicker
    [flopper_one-B_Cu.gbr, flopper_one-B_Mask.gbr, flopper_one-B_Paste.gbr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]
2026-02-12 ad st7789
    [flopper_one-B_Cu.gbr, flopper_one-B_Mask.gbr, flopper_one-B_Paste.gbr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]
2026-02-17 display is spi oops
    [flopper_one-B_Cu.gbr, flopper_one-B_Mask.gbr, flopper_one-B_Paste.gbr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]
2026-02-17 edit steps
    [flopper_one_assembly.step, flopper_one_case.step]
2026-02-17 better 3d model
    [esp32_Wroom_30pins_C-Type.STEP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]
2026-02-20 better materials
    [esp32_Wroom_30pins_C-Type.STEP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]
2026-02-20 redo renders
    [flopper_one-B_Cu.gbr, flopper_one-B_Mask.gbr, flopper_one-B_Paste.gbr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]
2026-02-20 the ultimate blender CI I guess
    [flopper_one-B_Cu.gbr, flopper_one-B_Mask.gbr, flopper_one-B_Paste.gbr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]
2026-02-22 rounded corners
    [flopper_one-B_Cu.gbr, flopper_one-B_Mask.gbr, flopper_one-B_Paste.gbr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]
2026-02-27 cosmetic pcb changes
    [flopper_one-B_Cu.gbr, flopper_one-B_Mask.gbr, flopper_one-B_Paste.gbr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]
2026-03-06 final gerbers...
    [flopper_one-B_Cu.gbr, flopper_one-B_Mask.gbr, flopper_one-B_Paste.gbr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]
2026-03-18 simplify a bunch because reordering pcb
    [flopper_one.kicad_pcb, flopper_one.kicad_sch]
2026-03-18 order it
    [flopper_one-B_Cu.gbr, flopper_one-B_Mask.gbr, flopper_one-B_Paste.gbr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]
